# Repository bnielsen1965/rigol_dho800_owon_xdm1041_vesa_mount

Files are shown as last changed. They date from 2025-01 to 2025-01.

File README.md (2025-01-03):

# Rigol DHO 800 plus Owon XDM 1041 Vesa mount

This project is a 3D printable vesa mounting bracket for the Rigol DHO 800 series 
digital oscilloscope with an Owon XDM 1041 digital multimeter mounted below the 
oscilloscope with probe storage hangers on the back.

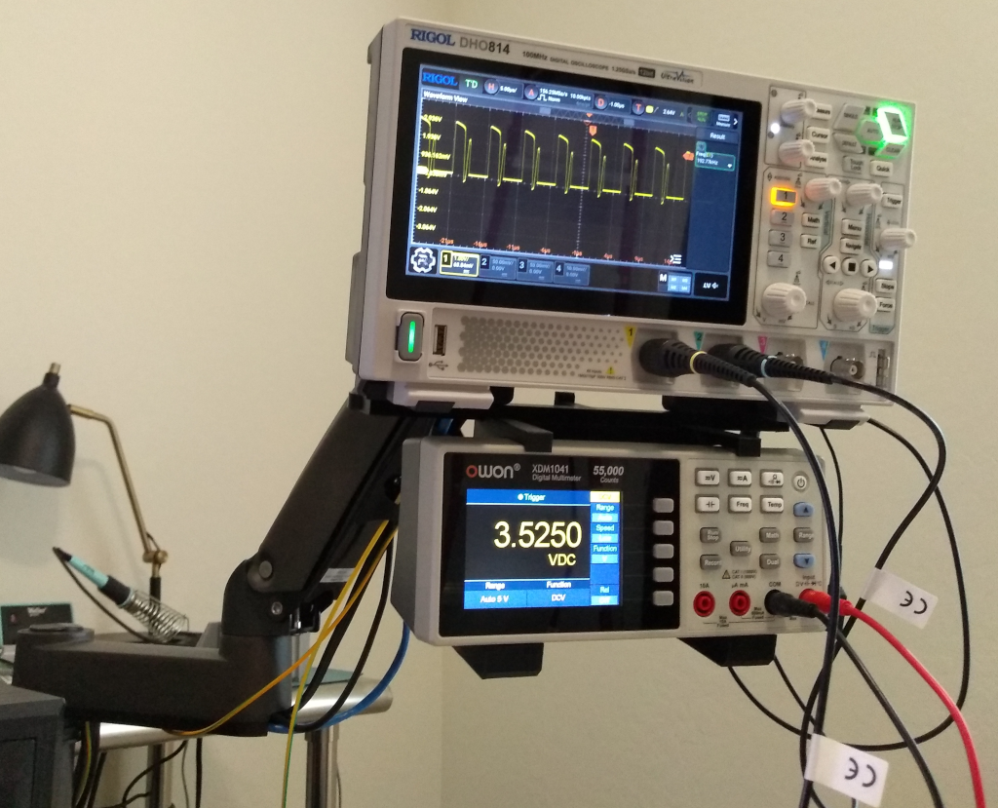
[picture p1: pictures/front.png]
Front view


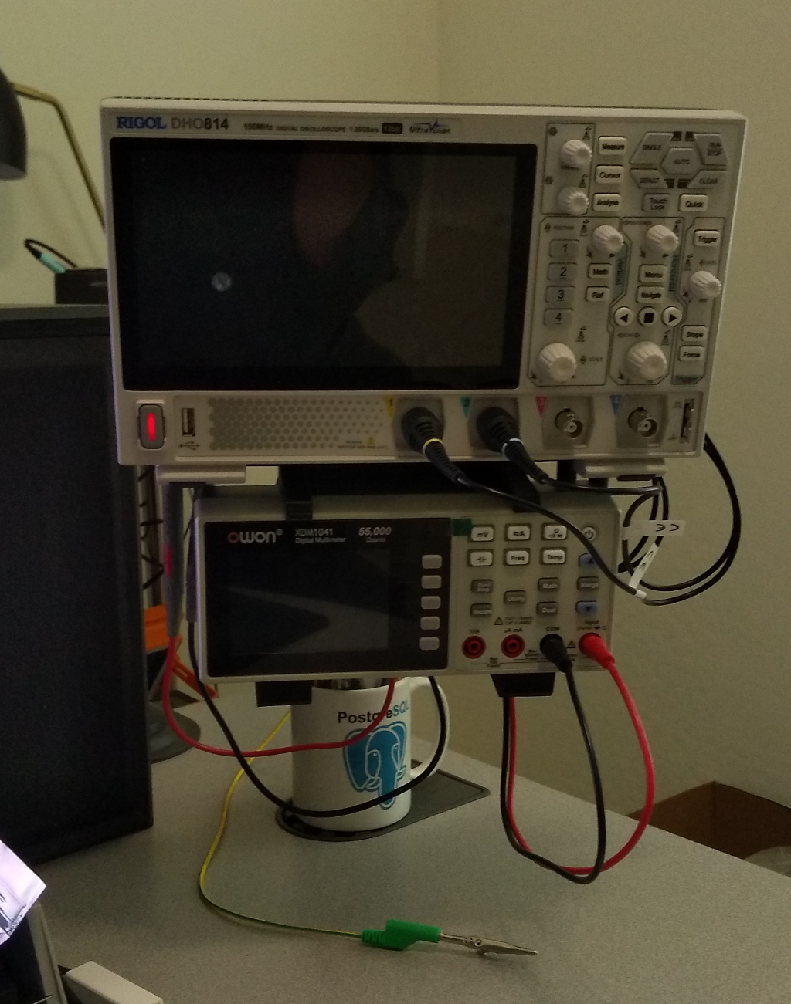
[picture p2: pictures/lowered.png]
Lowered view


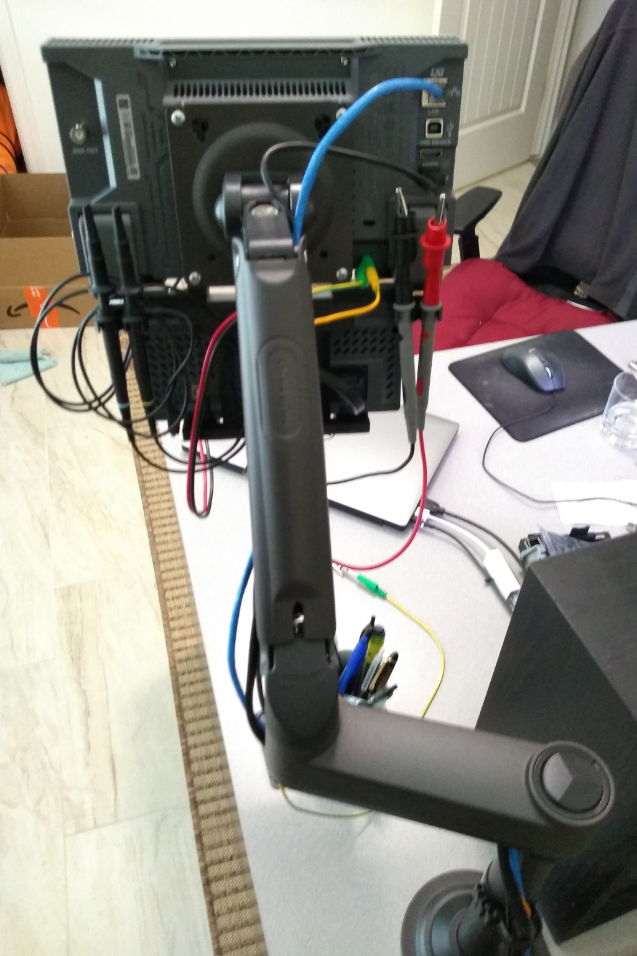
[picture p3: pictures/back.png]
Back view


# Files

The FreeCAD folder contains the 3D part designs for each 3D printed part.

The 3DSTL folder contains STL mesh files for use in a slicer.

# Materials

The materials for the bracket include the 3D printed parts, M4 6x6 thread inserts,
and a collection of M4 screws and washers.

Parts

* 3D printed parts
  * Base bracket for the bottom of the Owon meter
  * Top bracket for the top of the Owon meter
  * Back bracket to hold the base and top brackets together
  * Probe storage holder
  * Two L brackets with 100mm Vesa spacing for the Rigol Oscilloscope
  * Four standoff spacers for L brackets to Oscilloscope Vesa holes
* Hardware
  * 10 M4 6x6 threaded brass inserts
  * 8 M4 washers
  * 6 M4 x 16mm screws
  * 4 M4 x 20mm screws
  * 4 M4 x +30mm screws from Vesa mount

# Assembly

1. Bolt together the base bracket and back bracket.
2. Place Owon multimeter into the lower bracket then bolt the top bracket to the back bracket.
3. Bolt the probe storage holder to the top bracket.
4. Bolt the L brackets to the probe storage holder.
5. Bolt the assembled bracket to the Vesa mount and the Rigol oscilloscope with the spacers between the L brackets and the Rigol oscilloscope.

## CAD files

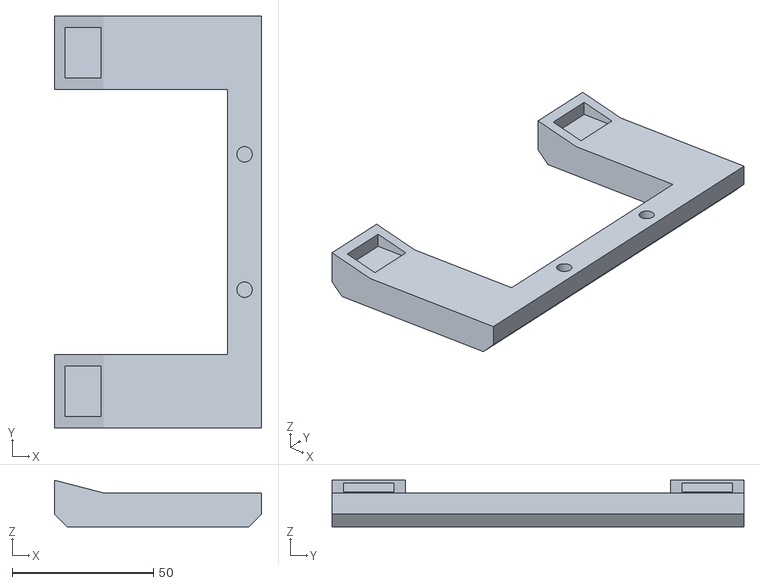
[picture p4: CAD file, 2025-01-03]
3DSTL/base-Body.stl
73.4 x 146.0 x 16.5

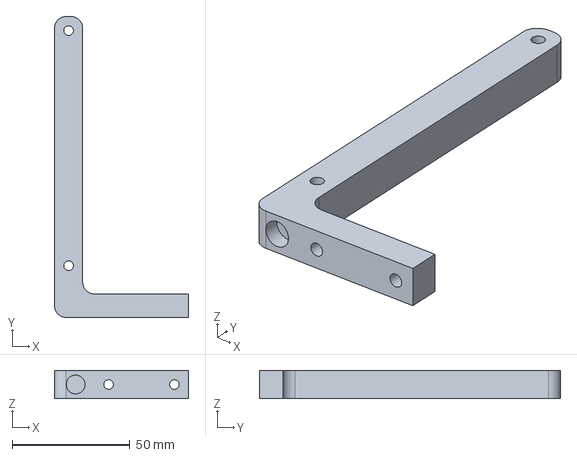
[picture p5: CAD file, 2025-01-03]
FreeCAD/vesa2.FCStd
57.0 x 128.0 x 12.0 mm

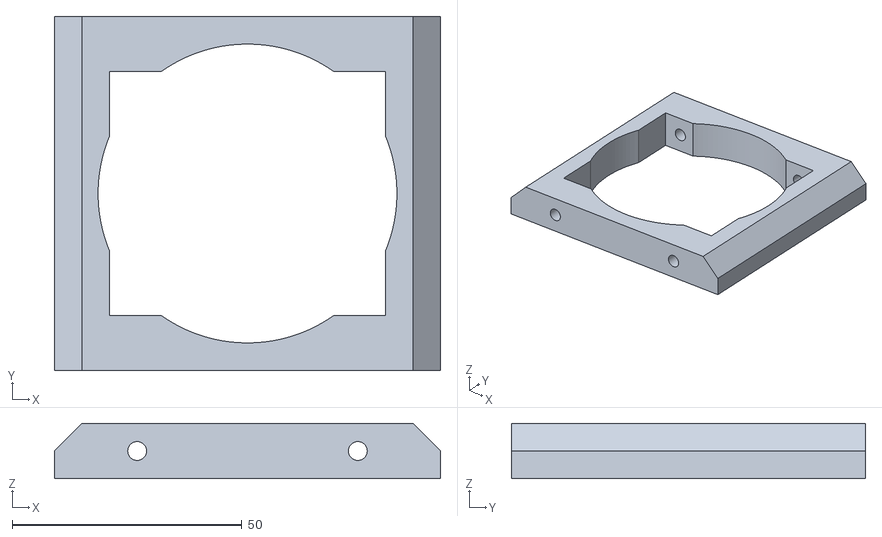
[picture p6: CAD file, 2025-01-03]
3DSTL/back-Body.stl
84.0 x 77.0 x 12.0

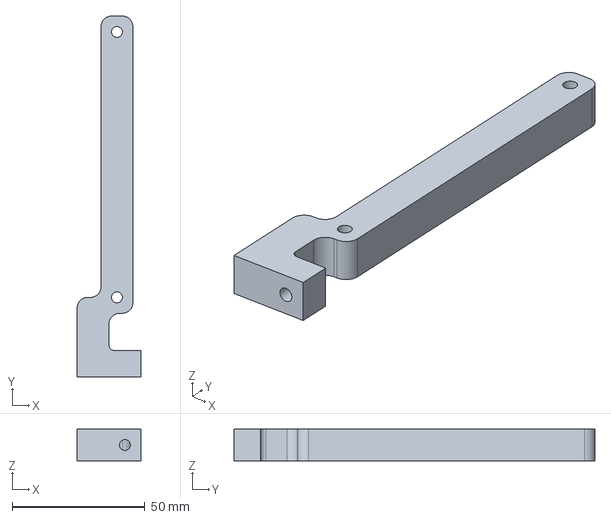
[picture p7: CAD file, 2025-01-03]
FreeCAD/vesa.FCStd
24.0 x 136.0 x 12.0 mm

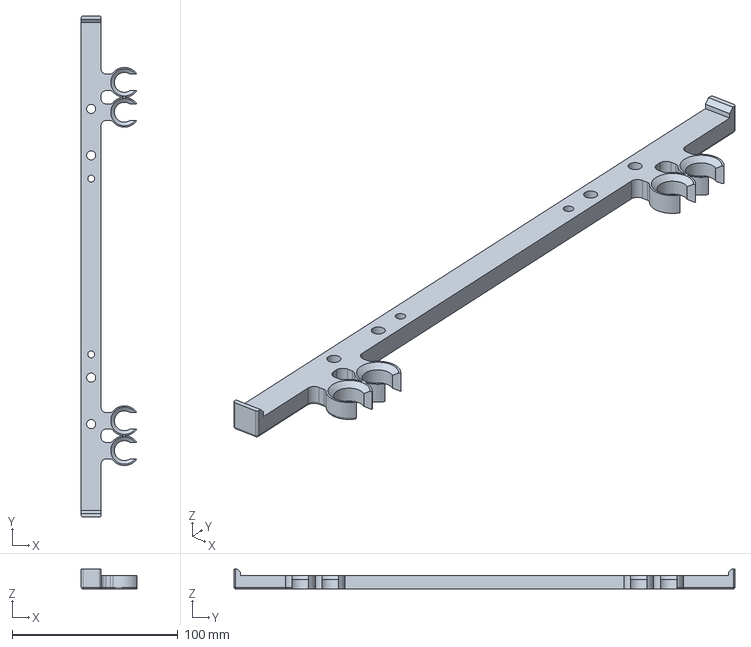
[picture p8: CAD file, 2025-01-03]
FreeCAD/holder.FCStd
33.5 x 302.0 x 12.0 mm

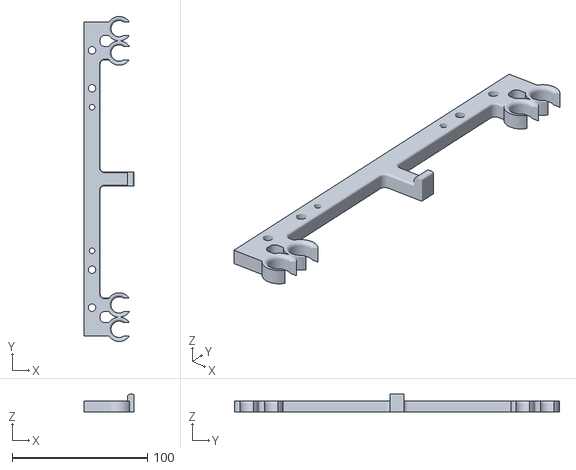
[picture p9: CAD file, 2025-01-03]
3DSTL/holder-Body.stl
37.0 x 240.0 x 13.0

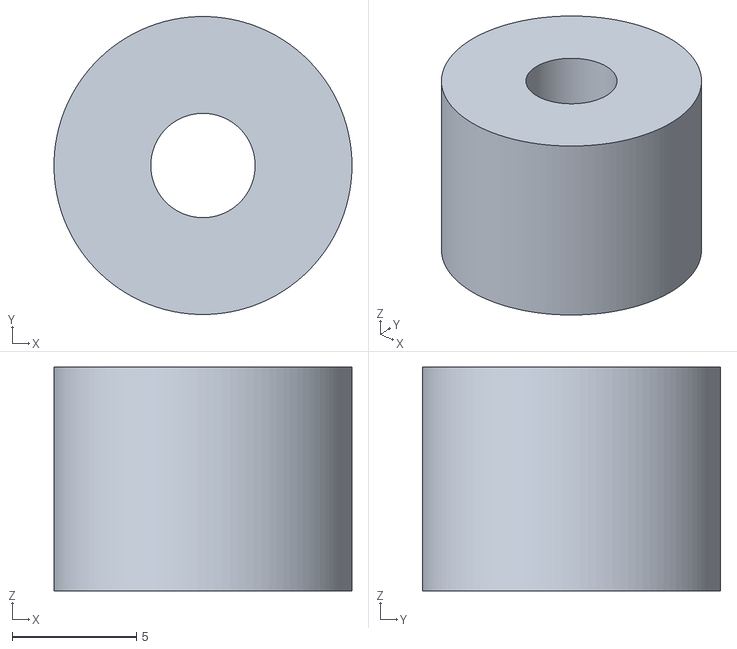
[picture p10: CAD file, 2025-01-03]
3DSTL/standoff-Body.stl
12.0 x 12.0 x 9.00

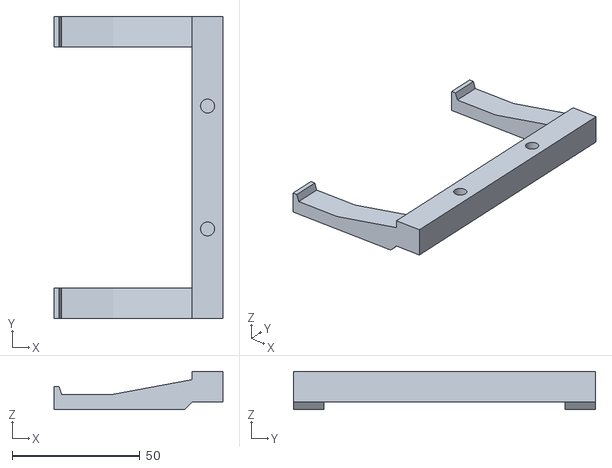
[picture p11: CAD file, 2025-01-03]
3DSTL/top-Body.stl
66.0 x 118.0 x 15.0

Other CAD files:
3DSTL/vesa2-Body.stl
FreeCAD/base.FCStd
FreeCAD/standoff.FCStd
3DSTL/vesa-Body.stl
FreeCAD/holder-recovered.FCStd
FreeCAD/back.FCStd
FreeCAD/top.FCStd

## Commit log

2025-01-03 Initial commit.
    [back-Body.stl, back.FCStd, base-Body.stl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]
2025-01-18 Update front image to show device activity, for fun.
